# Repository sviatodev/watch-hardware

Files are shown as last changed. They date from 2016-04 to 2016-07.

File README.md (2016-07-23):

# OLED Bluetooth 4.0 Watch
  - STM32L151 MCU with 128k Flash and 16k RAM
  - Bluetooth 4.0 HC-08 tranceiver
  - Piezoelectric buzzer
  - Vibration motor
  - Battery charging circuit
  - 3 buttons
  - BME280 weather sensor (temperature, pressure, humidity)
  - BMC150 3-axis accelerometer and 3-axis compass
  - OLED monochrome 128x64 I2C LCD
  - Micro USB socket (USB 3.0 socket part used for programmer SWD pins)
  - Socket for STM32F3Discovery ST-Link header (can be cut-off)

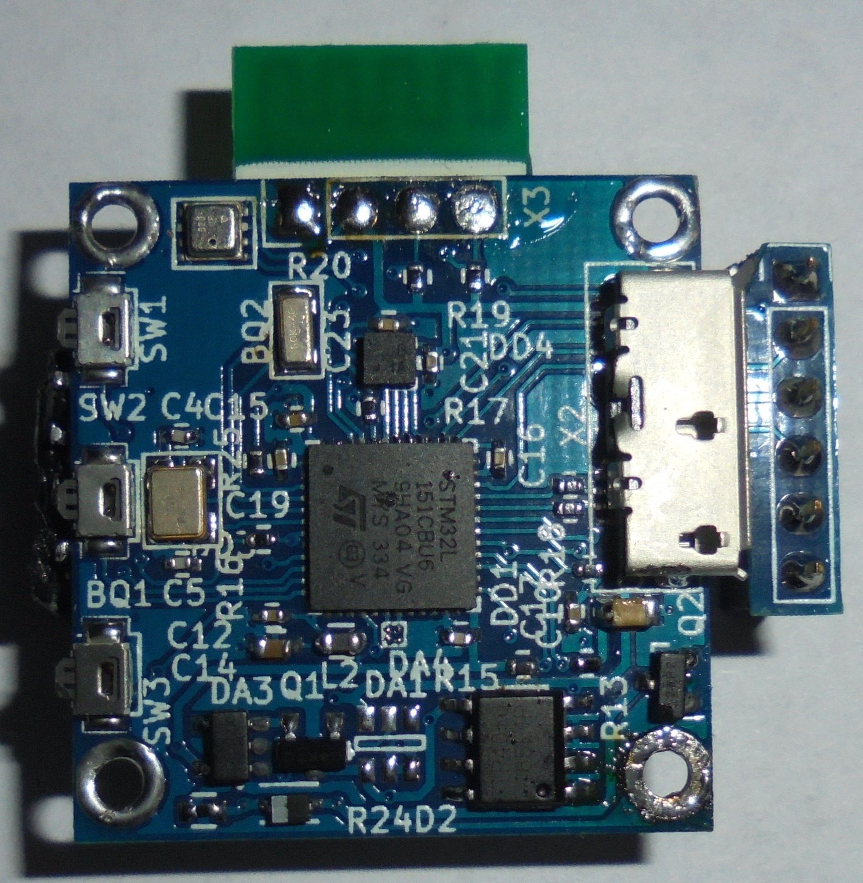
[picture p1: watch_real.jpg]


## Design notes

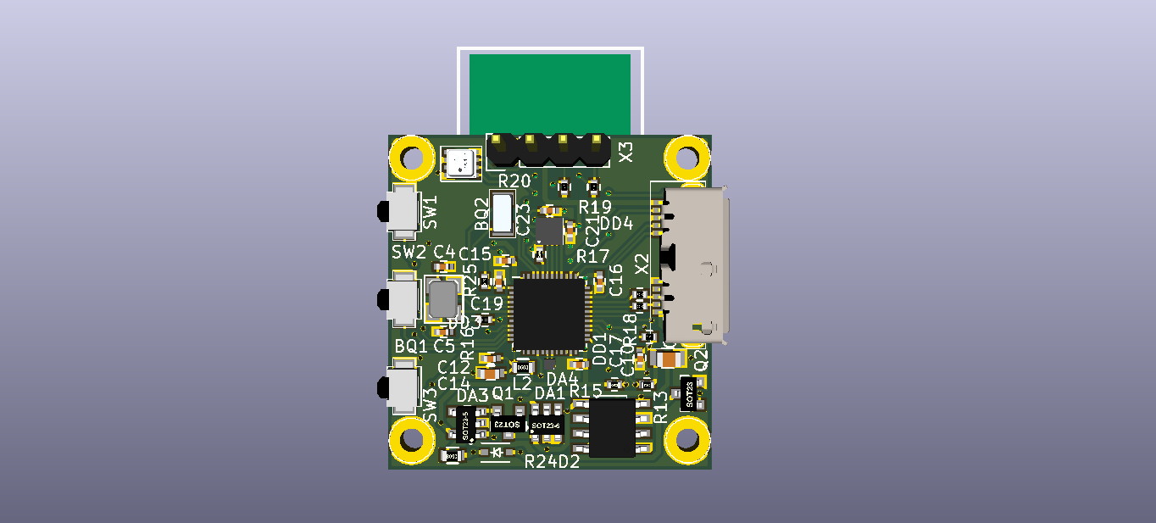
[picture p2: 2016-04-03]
watch_front.png

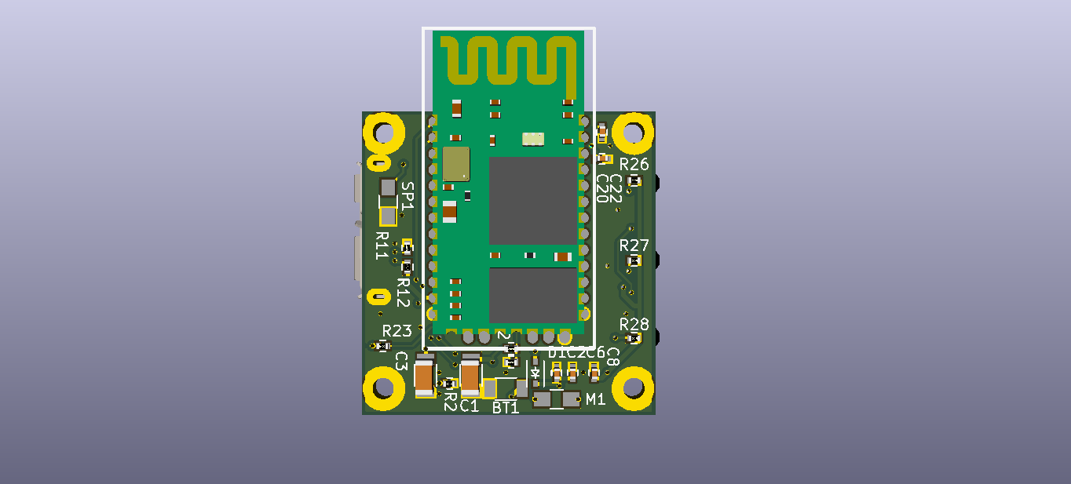
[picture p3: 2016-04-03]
watch_back.png

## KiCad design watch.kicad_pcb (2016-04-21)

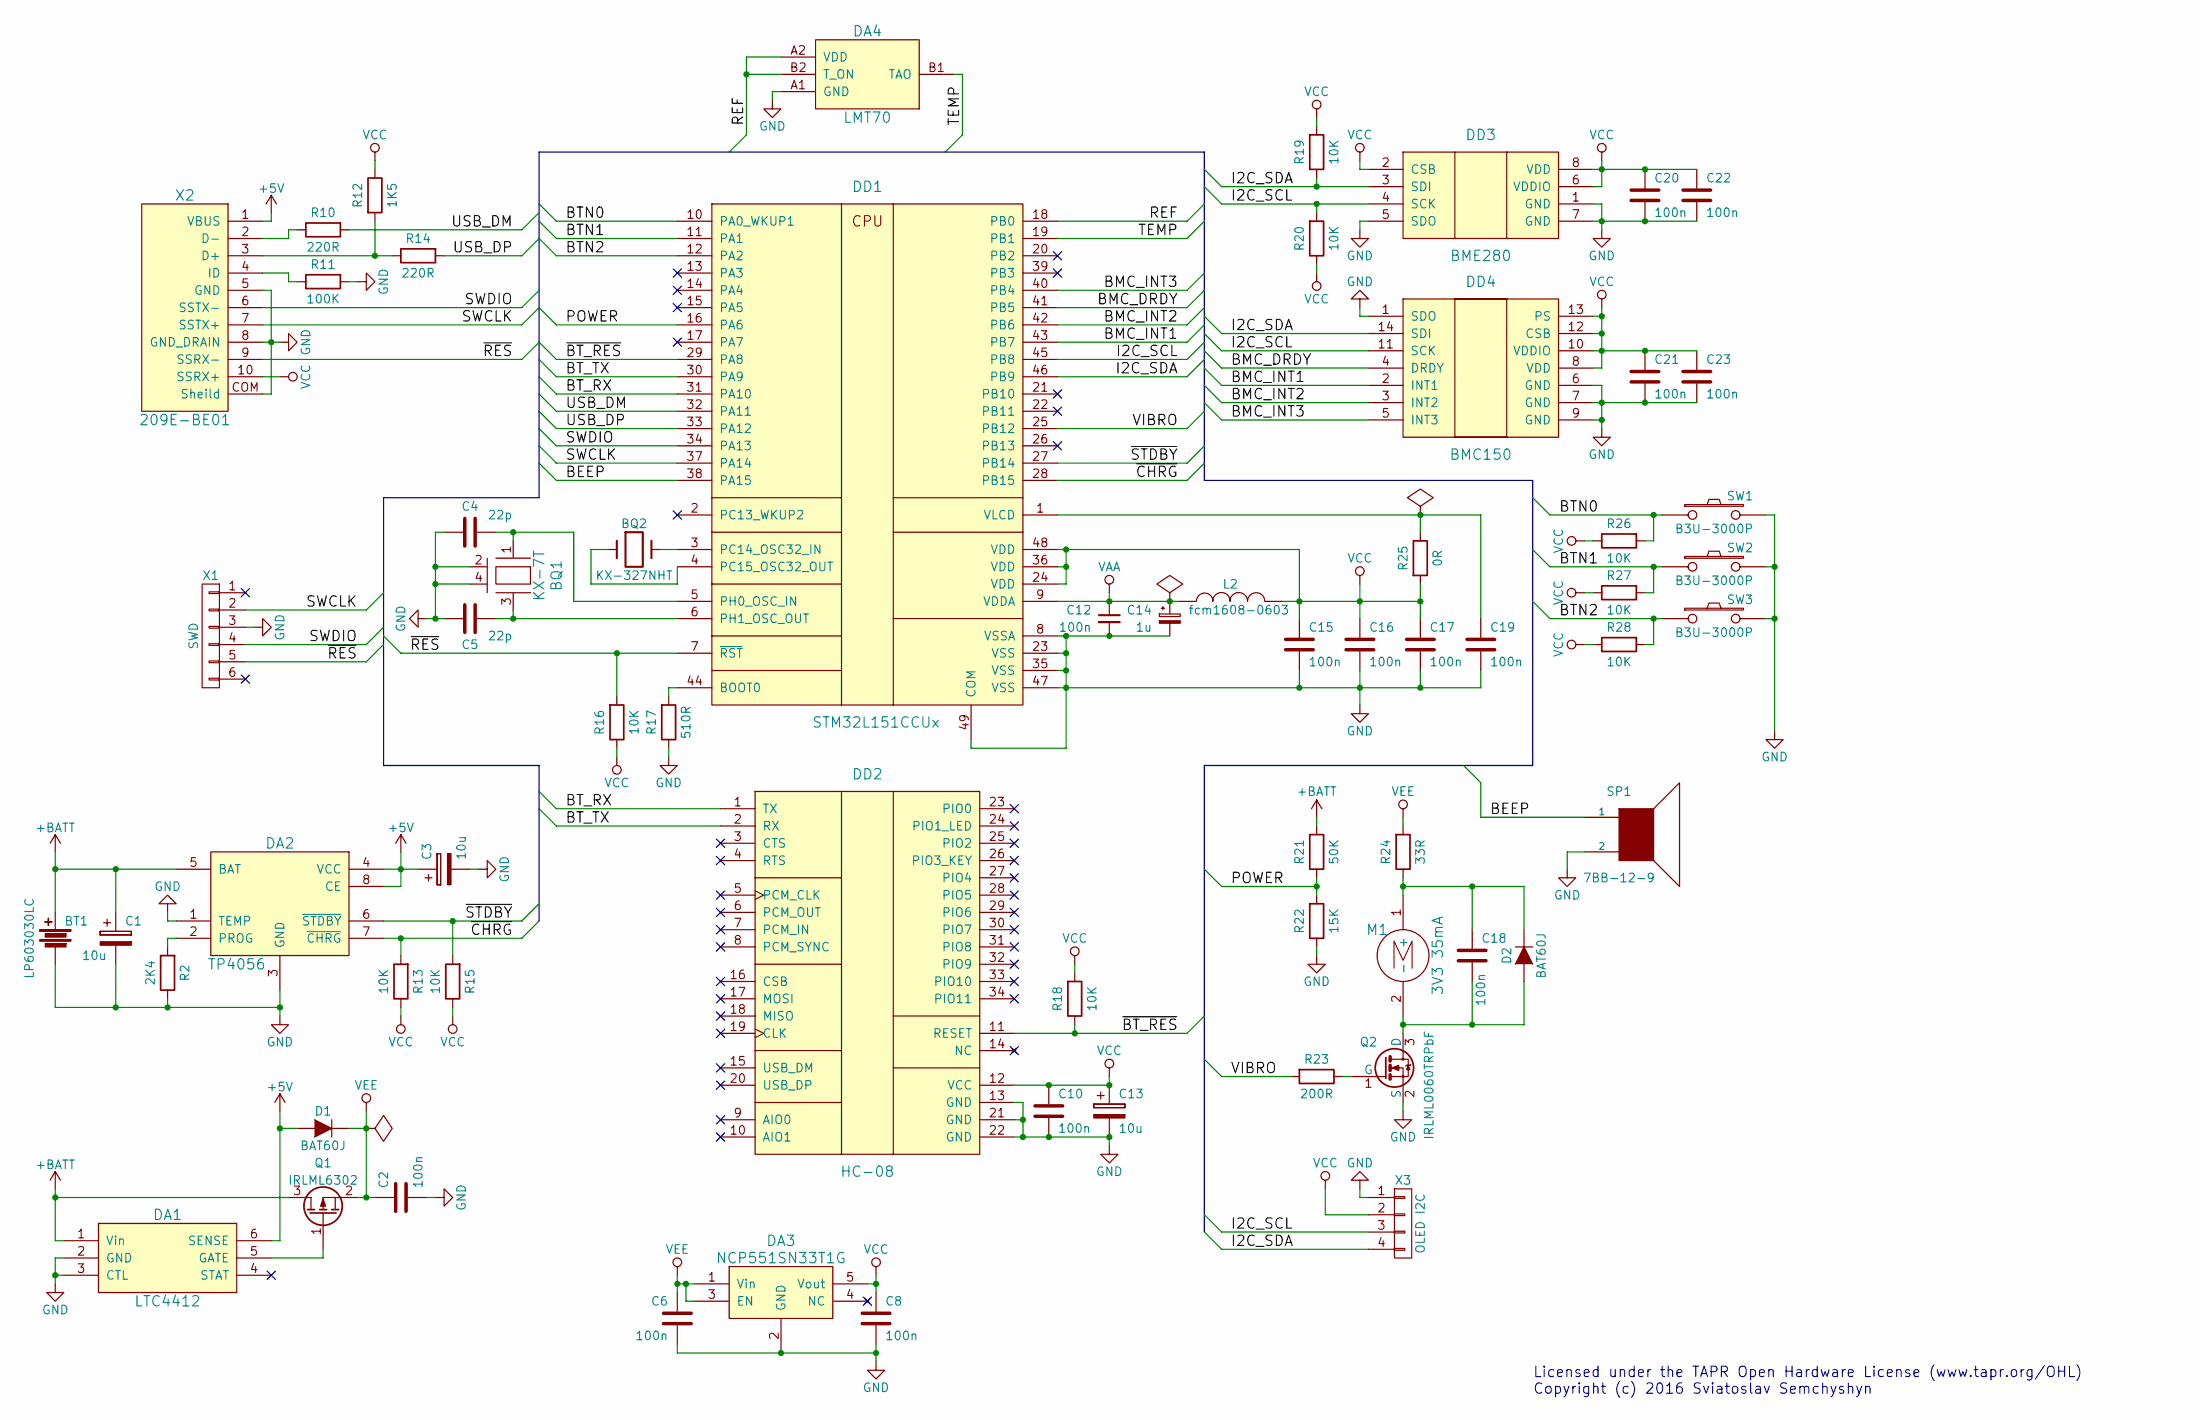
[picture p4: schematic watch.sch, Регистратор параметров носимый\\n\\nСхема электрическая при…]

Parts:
BQ1: KX-7T
BQ2: KX-327NHT
BT1: LP603030LC; R_0805_HandSoldering
C1, C3, C13: 10u; C_0805
C2, C6, C8, C10, C12, C15, C16, C17, C18, C19, C20, C21, C22, C23: 100n; C_0402
C4, C5: 22p; C_0402
C14: 1u; C_0603
D1, D2: BAT60J; SOD-323
DA1: LTC4412; SOT-23-6
DA2: TP4056; SOP-8
DA3: NCP551SN33T1G; SOT-23-5
DA4: LMT70; DSBGA4
DD1: STM32L151CCUx; QFN-48-1EP_7x7mm_Pitch0.5mm
DD2: HC-08
DD3: BME280
DD4: BMC150
L2: fcm1608-0603; R_0603
M1: 3V3 35mA; R_0805_HandSoldering
Q1: IRLML6302; SOT-23
Q2: IRLML0060TRPbF; SOT-23
R2: 2K4; R_0402
R10, R14: 220R; R_0402
R11: 100K; R_0402
R12: 1K5; R_0402
R13, R15, R16, R18, R19, R20, R26, R27, R28: 10K; R_0402
R17: 510R; R_0402
R21: 50K; R_0402
R22: 15K; R_0402
R23: 200R; R_0402
R24: 33R; R_0402
R25: 0R; R_0402
SP1: 7BB-12-9; R_0805_HandSoldering
SW1, SW2, SW3: B3U-3000P
X1: SWD; Pin_Header_Straight_1x06
X2: 209E-BE01
X3: OLED I2C; Pin_Header_Straight_1x04

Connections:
+5V: C3.1, D1.2 (A), DA1.6 (SENSE), DA2.4 (VCC), DA2.8 (CE), X2.1 (VBUS)
+BATT: BT1.1, C1.1, DA1.1 (Vin), DA2.5 (BAT), Q1.3 (D), R21.2
/BEEP: DD1.38 (PA15), SP1.1
/BMC_DRDY: DD1.41 (PB5), DD4.4 (DRDY)
/BMC_INT1: DD1.43 (PB7), DD4.2 (INT1)
/BMC_INT2: DD1.42 (PB6), DD4.3 (INT2)
/BMC_INT3: DD1.40 (PB4), DD4.5 (INT3)
/BTN0: DD1.10 (PA0_WKUP1), R26.2, SW1.1
/BTN1: DD1.11 (PA1), R27.2, SW2.1
/BTN2: DD1.12 (PA2), R28.2, SW3.1
/BT_RX: DD1.31 (PA10), DD2.1 (TX)
/BT_TX: DD1.30 (PA9), DD2.2 (RX)
/I2C_SCL: DD1.45 (PB8), DD3.4 (SCK), DD4.11 (SCK), R20.2, X3.3
/I2C_SDA: DD1.46 (PB9), DD3.3 (SDI), DD4.14 (SDI), R19.1, X3.4
/POWER: DD1.16 (PA6), R21.1, R22.2
/REF: DA4.A2 (VDD), DA4.B2 (T_ON), DD1.18 (PB0)
/SWCLK: DD1.37 (PA14), X1.2, X2.7 (SSTX+)
/SWDIO: DD1.34 (PA13), X1.4, X2.6 (SSTX-)
/TEMP: DA4.B1 (TAO), DD1.19 (PB1)
/USB_DM: DD1.32 (PA11), R10.2
/USB_DP: DD1.33 (PA12), R14.2
/VIBRO: DD1.25 (PB12), R23.2
/~BT_RES: DD1.29 (PA8), DD2.11 (RESET), R18.1
/~CHRG: DA2.7 (~CHRG), DD1.28 (PB15), R13.2
/~RES: DD1.7 (~RST), R16.2, X1.5, X2.9 (SSRX-)
/~STDBY: DA2.6 (~STDBY), DD1.27 (PB14), R15.2
GND: BQ1.2, BQ1.4, BT1.2, C1.2, C2.2, C3.2, C4.2, C5.2, C6.2, C8.2, C10.2, C12.2, C13.2, C14.2, C15.2, C16.2, C17.2, C19.2, C20.2, C21.2, C22.2, C23.2, DA1.2 (GND), DA1.3 (CTL), DA2.1 (TEMP), DA2.3 (GND), DA3.2 (GND), DA4.A1 (GND), DD1.8 (VSSA), DD1.23 (VSS), DD1.35 (VSS), DD1.47 (VSS), DD1.49 (COM), DD2.13 (GND), DD2.21 (GND), DD2.22 (GND), DD3.1 (GND), DD3.5 (SDO), DD3.7 (GND), DD4.1 (SDO), DD4.6 (GND), DD4.7 (GND), DD4.9 (GND), Q2.2 (S), R2.1, R11.2, R17.1, R22.1, SP1.2, SW1.2, SW2.2, SW3.2, X1.3, X2.5 (GND), X2.8 (GND_DRAIN), X2.COM (Sheild), X3.1
unnamed: BQ1.1, C4.1, DD1.5 (PH0_OSC_IN)
unnamed: BQ1.3, C5.1, DD1.6 (PH1_OSC_OUT)
unnamed: BQ2.1, DD1.4 (PC15_OSC32_OUT)
unnamed: BQ2.2, DD1.3 (PC14_OSC32_IN)
unnamed: C18.1, D2.1 (K), M1.1 (+), R24.1
unnamed: C18.2, D2.2 (A), M1.2 (-), Q2.3 (D)
unnamed: C19.1, DD1.1 (VLCD), R25.1
unnamed: DA1.5 (GATE), Q1.1 (G)
unnamed: DA2.2 (PROG), R2.2
unnamed: DD1.44 (BOOT0), R17.2
unnamed: Q2.1 (G), R23.1
unnamed: R10.1, X2.2 (D-)
unnamed: R11.1, X2.4 (ID)
unnamed: R12.2, R14.1, X2.3 (D+)
VAA: C12.1, C14.1, DD1.9 (VDDA), L2.1
VCC: C8.1, C10.1, C13.1, C15.1, C16.1, C17.1, C20.1, C21.1, C22.1, C23.1, DA3.5 (Vout), DD1.24 (VDD), DD1.36 (VDD), DD1.48 (VDD), DD2.12 (VCC), DD3.2 (CSB), DD3.6 (VDDIO), DD3.8 (VDD), DD4.8 (VDD), DD4.10 (VDDIO), DD4.12 (CSB), DD4.13 (PS), L2.2, R12.1, R13.1, R15.1, R16.1, R18.2, R19.2, R20.1, R25.2, R26.1, R27.1, R28.1, X2.10 (SSRX+), X3.2
VEE: C2.1, C6.1, D1.1 (K), DA3.1 (Vin), DA3.3 (EN), Q1.2 (S), R24.2

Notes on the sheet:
Licensed under the TAPR Open Hardware License (www.tapr.org/OHL) Copyright (c) 2016 Sviatoslav Semchyshyn

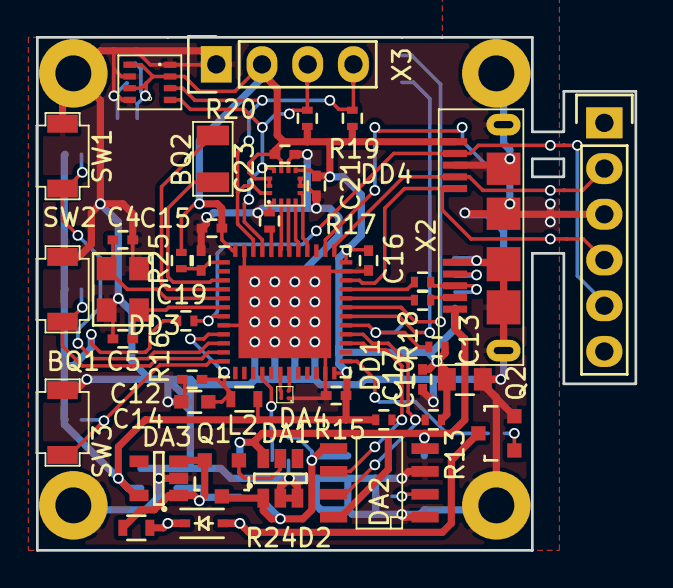
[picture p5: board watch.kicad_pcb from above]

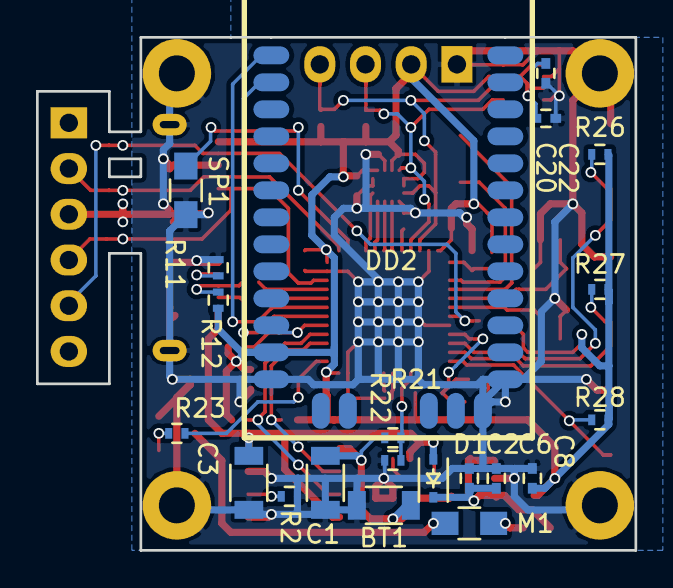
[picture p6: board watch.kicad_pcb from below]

Board: 2 copper layers, 33.2 x 28.5 mm, 63 parts (21 on the bottom side), 44 nets.

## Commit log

2016-04-02 Update LICENSE
    Switch project to TAPR Open Hardware License
2016-04-02 PCB Changed
    [watch.kicad_pcb]
2016-04-03 PCB finished, some changes in schematic
    [watch.kicad_pcb, watch.sch]
2016-04-03 Some small PCB changes
    [watch.kicad_pcb]
2016-04-04 Modified libraries path
    [watch.kicad_pcb]
2016-04-04 Paths changed
    [watch.kicad_pcb]
2016-04-04 Add flash connector for stm32f3discovery stlink
    [watch.kicad_pcb, watch.sch]
2016-04-21 Fixed MCU footprint
    [watch.kicad_pcb, watch.sch]
2016-05-16 Add photo of real board
